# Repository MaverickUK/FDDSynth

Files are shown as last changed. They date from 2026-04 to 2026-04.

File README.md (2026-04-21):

# HDD Synth
<div style="background: white; display: inline-block; padding: 8px;">
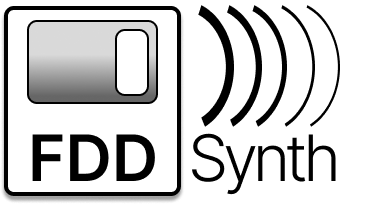
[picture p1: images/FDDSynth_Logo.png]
  
</div>

### Recreates the sound of mechanical spinning FDDs on retro PCs that use a solid state floppy drive.

The first project I created was the [HDD Synth](https://github.com/MaverickUK/HDDSynth) and so bringing the sound back to floppy disk drives felt like the next logical step.

The FDD Synth listens to the signals on the FDD cable that indicate when the motor is spinning and when the head is moving. It essentially recreates those physical actions in software, meaning that when the FDD motor starts spinning the disk it'll play a short spinup sound before a looping spin sound continues. FDD head movement is monitored and replicated with a short click for small movement along with hum of move rapid track changes. 

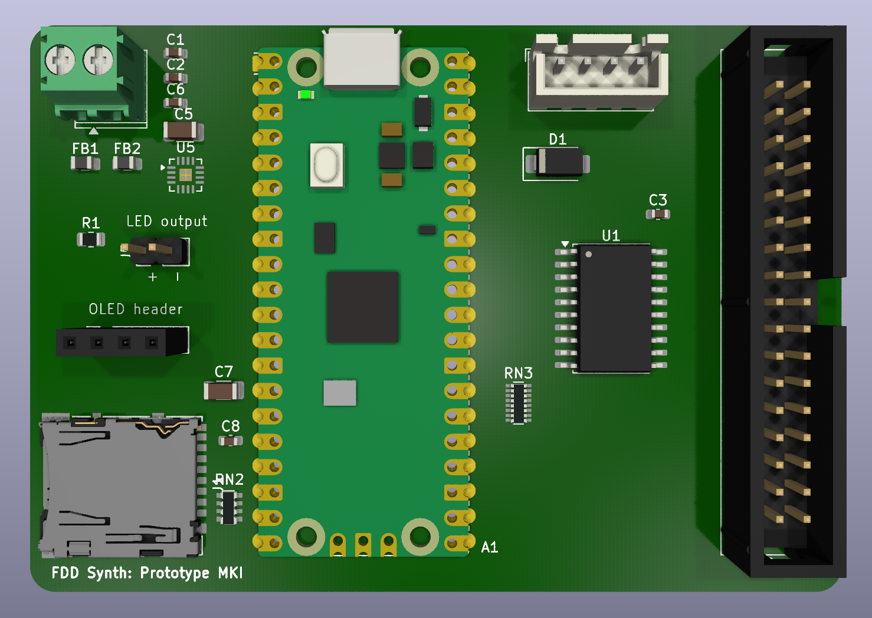
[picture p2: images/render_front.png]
FDD Synth PCB front

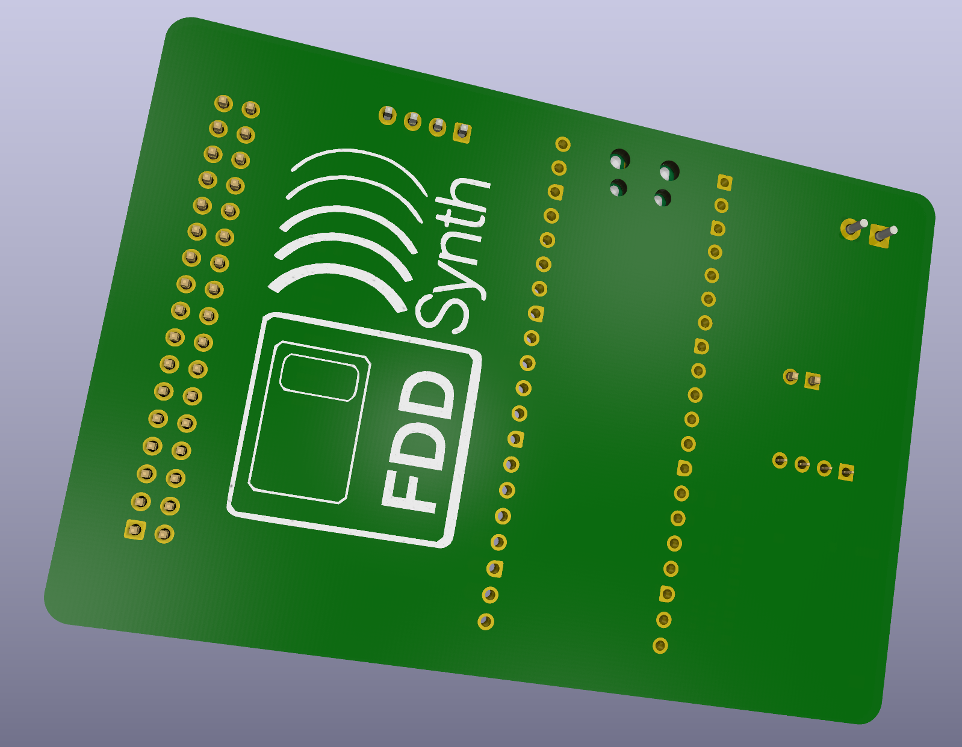
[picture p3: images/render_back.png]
FDD Synth PCB back


## Features

- **Plug and Play**: Uses FDD cable to monitor the exact FDD activity, so all you have to do it plug it in
- **SD Card Storage**: Audio samples stored on removable SD card for easy customization
- **Configurable**: Future software based enhancements planned

## Progress
### 🔄  Phase 1: Breadboard prototype
### 🔄 Phase 2: PCB prototype
### 🌱 Phase 3: PCB final 

<!-- ## Media
[View gallery](media.md) -->

## Contact
Peter Bridger at [maverickuk@gmail.com](maverickuk@gmail.com)

<!--
## Resources

## Acknowledgments
-->

## License
This project is licensed under the GNU General Public License v3.0.

- **Permissions:** Commercial use, modification, and distribution are allowed.
- **Conditions:** You must include a copy of the license and the source code for any derivative works.
- **Prohibitions:** You cannot close the source or use a different license for derivative works.

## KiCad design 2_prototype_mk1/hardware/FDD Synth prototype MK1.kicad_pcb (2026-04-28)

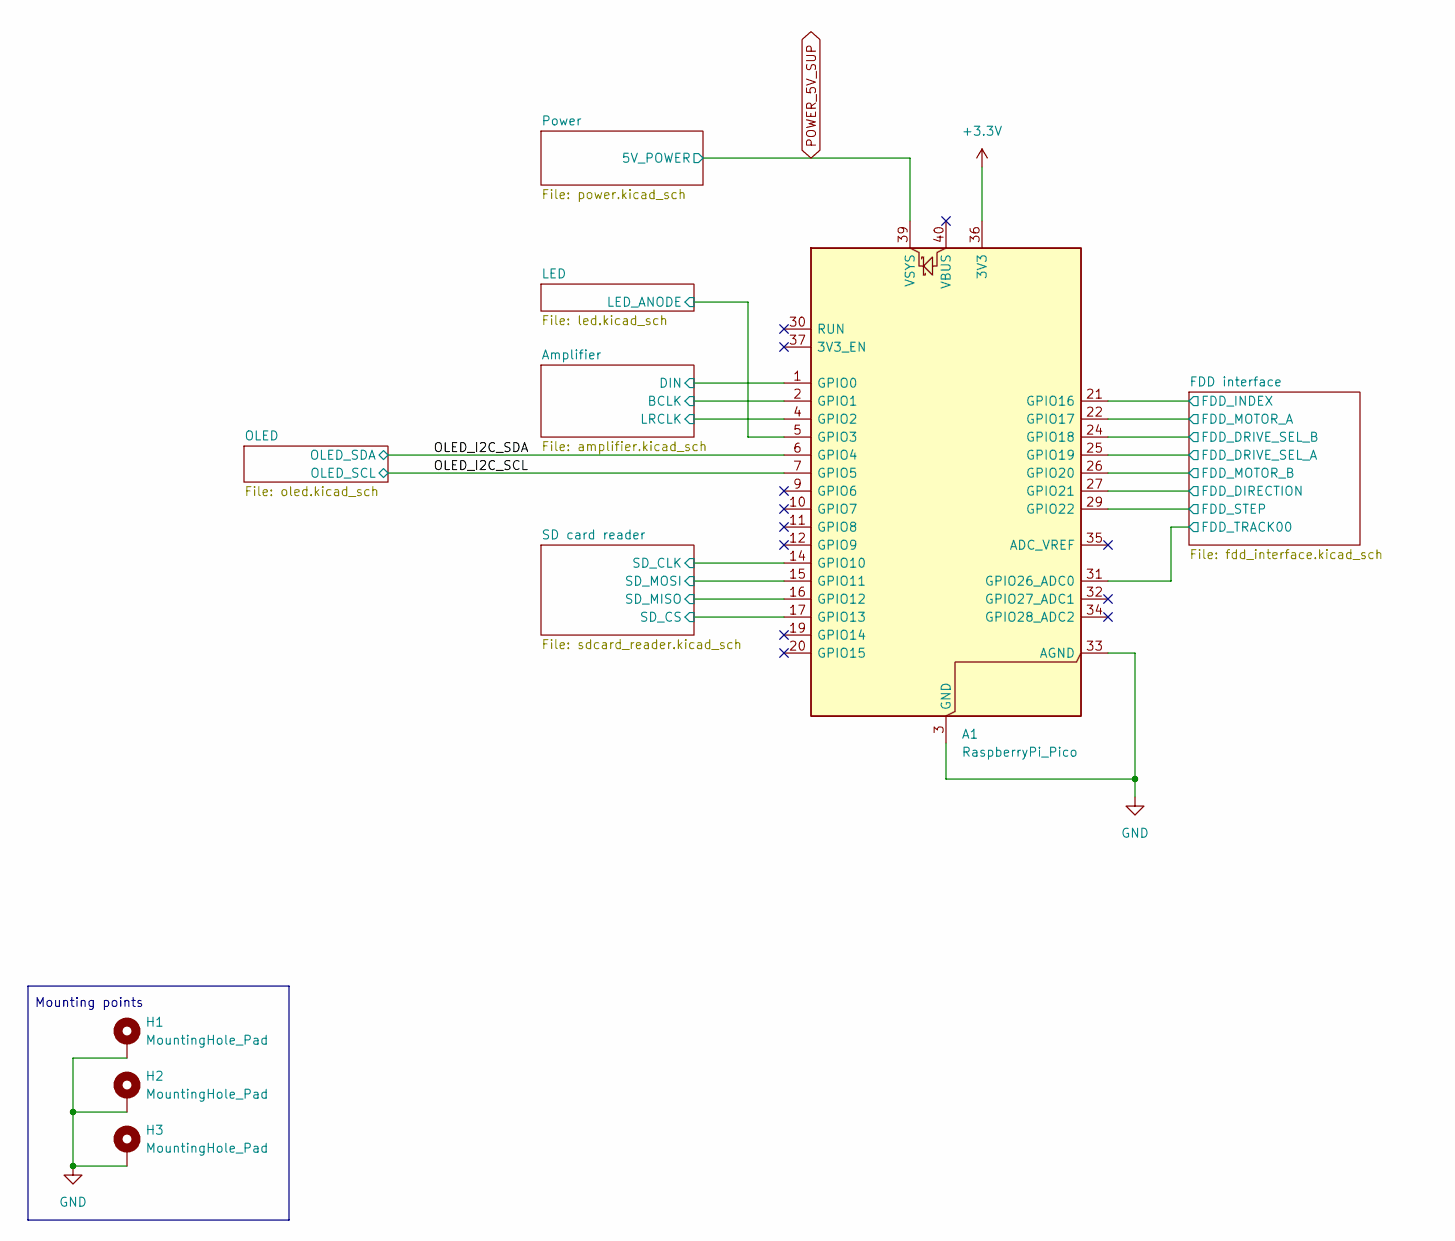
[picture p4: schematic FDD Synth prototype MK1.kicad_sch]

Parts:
A1: RaspberryPi_Pico; RaspberryPi_Pico_Common_Unspecified
H1, H2, H3: MountingHole_Pad; MountingHole_3.2mm_M3_Pad_Via

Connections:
+3.3V: A1.36 (3V3); also elsewhere on the board
/Amplifier/BCLK: A1.2 (GPIO1); also elsewhere on the board
/Amplifier/DIN: A1.1 (GPIO0); also elsewhere on the board
/Amplifier/LRCLK: A1.4 (GPIO2); also elsewhere on the board
/FDD interface/FDD_DIRECTION: A1.27 (GPIO21); also elsewhere on the board
/FDD interface/FDD_DRIVE_SEL_A: A1.25 (GPIO19); also elsewhere on the board
/FDD interface/FDD_DRIVE_SEL_B: A1.24 (GPIO18); also elsewhere on the board
/FDD interface/FDD_INDEX: A1.21 (GPIO16); also elsewhere on the board
/FDD interface/FDD_MOTOR_A: A1.22 (GPIO17); also elsewhere on the board
/FDD interface/FDD_MOTOR_B: A1.26 (GPIO20); also elsewhere on the board
/FDD interface/FDD_STEP: A1.29 (GPIO22); also elsewhere on the board
/FDD interface/FDD_TRACK00: A1.31 (GPIO26_ADC0); also elsewhere on the board
/LED/LED_ANODE: A1.5 (GPIO3); also elsewhere on the board
/OLED_I2C_SCL: A1.7 (GPIO5); also elsewhere on the board
/OLED_I2C_SDA: A1.6 (GPIO4); also elsewhere on the board
/SD card reader/SD_CLK: A1.14 (GPIO10); also elsewhere on the board
/SD card reader/SD_CS: A1.17 (GPIO13); also elsewhere on the board
/SD card reader/SD_MISO: A1.16 (GPIO12); also elsewhere on the board
/SD card reader/SD_MOSI: A1.15 (GPIO11); also elsewhere on the board
GND: A1.3 (GND), A1.8 (GND), A1.13 (GND), A1.18 (GND), A1.23 (GND), A1.28 (GND), A1.33 (AGND), A1.38 (GND), H1.1 (1_1), H2.1 (1_1), H3.1 (1_1); also elsewhere on the board
POWER_5V_SUP: A1.39 (VSYS); also elsewhere on the board

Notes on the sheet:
Mounting points

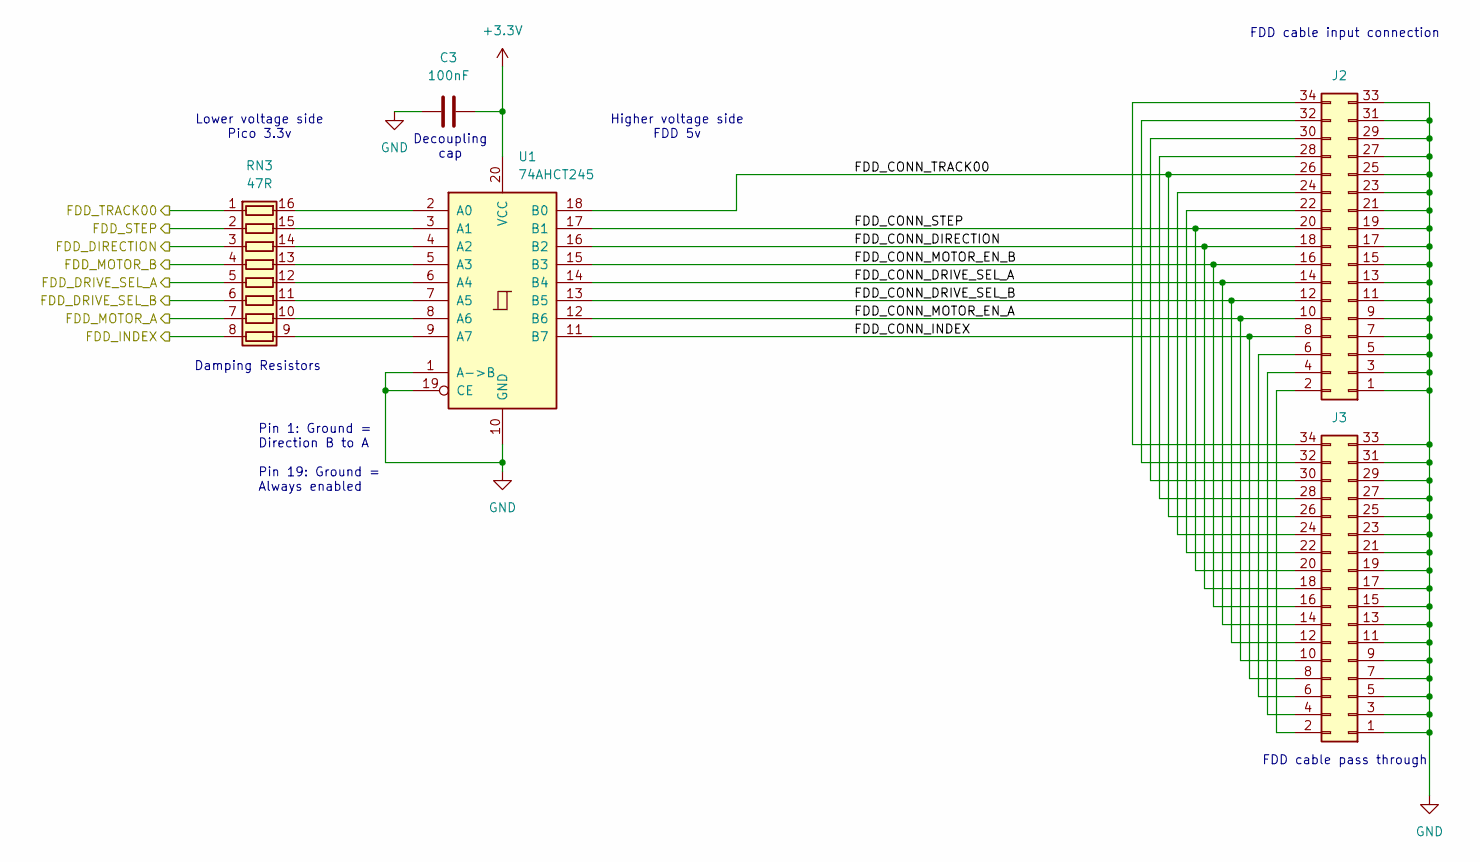
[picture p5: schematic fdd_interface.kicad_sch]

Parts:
C3: 100nF; C_0603_1608Metric
J2, J3: Conn_02x17_Odd_Even; IDC-Header_2x17_P2.54mm_Vertical
RN3: 47R; R_Array_Convex_8x0602
U1: 74AHCT245; SOIC-20W_7.5x12.8mm_P1.27mm

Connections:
+3.3V: C3.2, U1.20 (VCC); also elsewhere on the board
/FDD interface/FDD_CONN_DIRECTION: J2.18, J3.18, U1.16 (B2)
/FDD interface/FDD_CONN_DRIVE_SEL_A: J2.14, J3.14, U1.14 (B4)
/FDD interface/FDD_CONN_DRIVE_SEL_B: J2.12, J3.12, U1.13 (B5)
/FDD interface/FDD_CONN_INDEX: J2.8, J3.8, U1.11 (B7)
/FDD interface/FDD_CONN_MOTOR_EN_A: J2.10, J3.10, U1.12 (B6)
/FDD interface/FDD_CONN_MOTOR_EN_B: J2.16, J3.16, U1.15 (B3)
/FDD interface/FDD_CONN_STEP: J2.20, J3.20, U1.17 (B1)
/FDD interface/FDD_CONN_TRACK00: J2.26, J3.26, U1.18 (B0)
/FDD interface/FDD_DIRECTION: RN3.3 (R3.1); also elsewhere on the board
/FDD interface/FDD_DRIVE_SEL_A: RN3.5 (R5.1); also elsewhere on the board
/FDD interface/FDD_DRIVE_SEL_B: RN3.6 (R6.1); also elsewhere on the board
/FDD interface/FDD_INDEX: RN3.8 (R8.1); also elsewhere on the board
/FDD interface/FDD_MOTOR_A: RN3.7 (R7.1); also elsewhere on the board
/FDD interface/FDD_MOTOR_B: RN3.4 (R4.1); also elsewhere on the board
/FDD interface/FDD_STEP: RN3.2 (R2.1); also elsewhere on the board
/FDD interface/FDD_TRACK00: RN3.1 (R1.1); also elsewhere on the board
GND: C3.1, J2.1, J2.3, J2.5, J2.7, J2.9, J2.11, J2.13, J2.15, J2.17, J2.19, J2.21, J2.23, J2.25, J2.27, J2.29, J2.31, J2.33, J3.1, J3.3, J3.5, J3.7, J3.9, J3.11, J3.13, J3.15, J3.17, J3.19, J3.21, J3.23, J3.25, J3.27, J3.29, J3.31, J3.33, U1.1 (A->B), U1.10 (GND), U1.19 (CE); also elsewhere on the board
unnamed: J2.2, J3.2
unnamed: J2.4, J3.4
unnamed: J2.6, J3.6
unnamed: J2.22, J3.22
unnamed: J2.24, J3.24
unnamed: J2.28, J3.28
unnamed: J2.30, J3.30
unnamed: J2.32, J3.32
unnamed: J2.34, J3.34
unnamed: RN3.16 (R1.2), U1.2 (A0)
unnamed: RN3.15 (R2.2), U1.3 (A1)
unnamed: RN3.14 (R3.2), U1.4 (A2)
unnamed: RN3.13 (R4.2), U1.5 (A3)
unnamed: RN3.12 (R5.2), U1.6 (A4)
unnamed: RN3.11 (R6.2), U1.7 (A5)
unnamed: RN3.10 (R7.2), U1.8 (A6)
unnamed: RN3.9 (R8.2), U1.9 (A7)

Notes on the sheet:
Pin 1: Ground = Direction B to A Pin 19: Ground = Always enabled
Decoupling cap
Damping Resistors
Lower voltage side Pico 3.3v
Higher voltage side FDD 5v
FDD cable input connection
FDD cable pass through

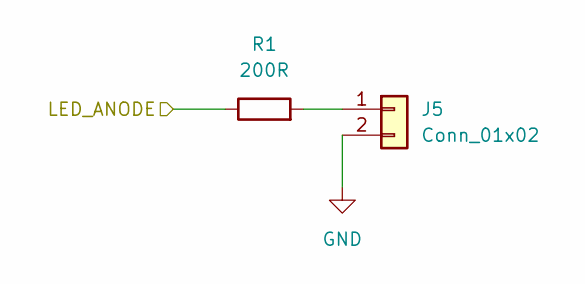
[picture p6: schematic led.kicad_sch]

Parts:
J5: Conn_01x02; PinHeader_1x02_P2.54mm_Vertical
R1: 200R; R_0805_2012Metric

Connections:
/LED/LED_ANODE: R1.1; also elsewhere on the board
GND: J5.2; also elsewhere on the board
unnamed: J5.1, R1.2

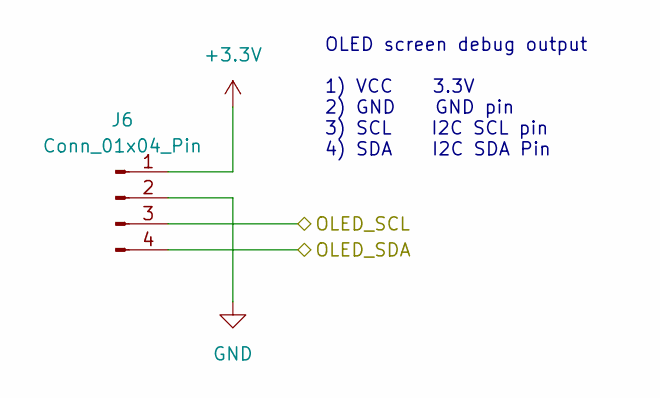
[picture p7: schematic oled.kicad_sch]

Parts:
J6: Conn_01x04_Pin; PinSocket_1x04_P2.54mm_Vertical

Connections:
+3.3V: J6.1; also elsewhere on the board
/OLED_I2C_SCL: J6.3; also elsewhere on the board
/OLED_I2C_SDA: J6.4; also elsewhere on the board
GND: J6.2; also elsewhere on the board

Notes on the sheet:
OLED screen debug output 1) VCC 3.3V 2) GND GND pin 3) SCL I2C SCL pin 4) SDA I2C SDA Pin

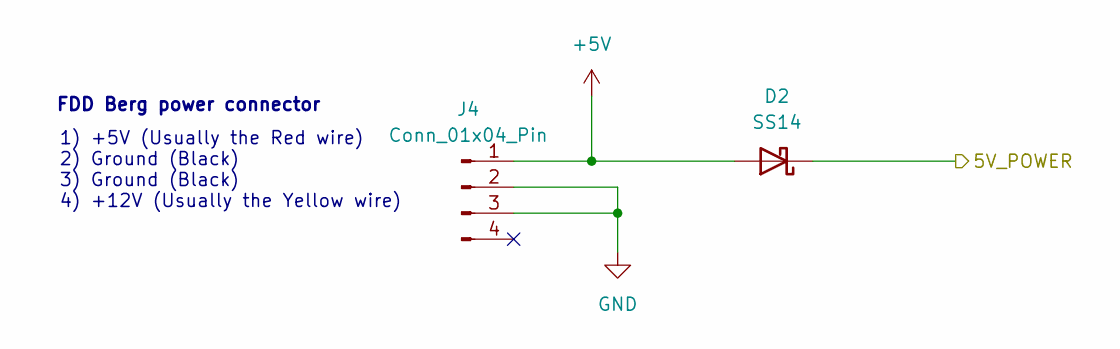
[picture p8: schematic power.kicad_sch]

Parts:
D2: SS14; D_SMA
J4: Conn_01x04_Pin; Molex_KK-254_AE-6410-04A_1x04_P2.54mm_Vertical

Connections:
+5V: D2.2 (A), J4.1
GND: J4.2, J4.3; also elsewhere on the board
POWER_5V_SUP: D2.1 (K); also elsewhere on the board

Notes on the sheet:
FDD Berg power connector
1) +5V (Usually the Red wire) 2) Ground (Black) 3) Ground (Black) 4) +12V (Usually the Yellow wire)

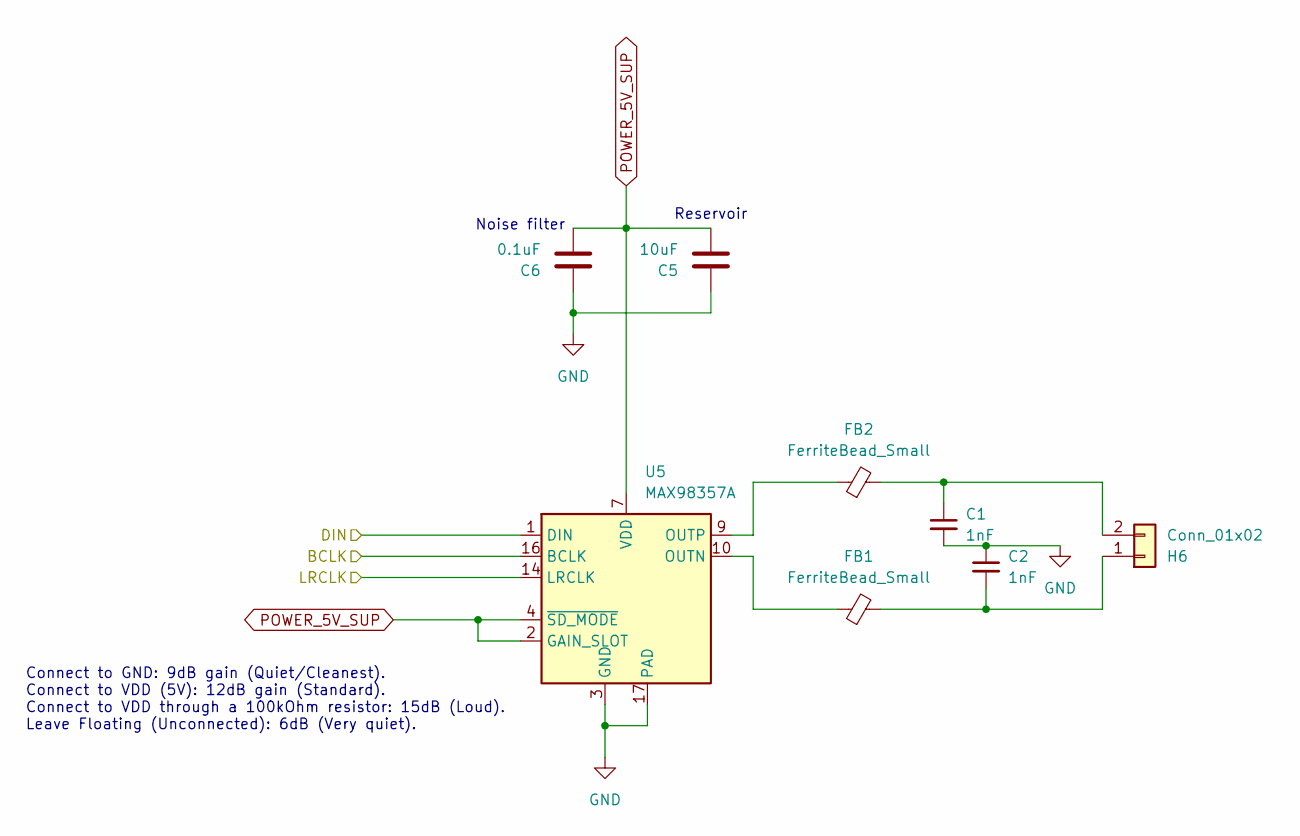
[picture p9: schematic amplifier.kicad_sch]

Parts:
C1, C2: 1nF; C_0603_1608Metric; Manufacturer_Part_Number 0603B102K500NT
C5: 10uF; C_1206_3216Metric; Manufacturer_Part_Number CL31A106KAHNNNE
C6: 0.1uF; C_0603_1608Metric; Manufacturer_Part_Number CL10B104KO8NNNC
FB1, FB2: FerriteBead_Small; L_0805_2012Metric; Manufacturer_Part_Number BLM21PG221SN1D; LCSC_Part_Number C85840
H6: Conn_01x02; TerminalBlock_Phoenix_PT-1,5-2-3.5-H_1x02_P3.50mm_Horizontal; Manufacturer_Part_Number 1984617; LCSC_Part_Number C3819527
U5: MAX98357A; TQFN-16-1EP_3x3mm_P0.5mm_EP1.23x1.23mm; Manufacturer_Part_Number MAX98357AETE+T; LCSC_Part_Number C910544

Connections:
/Amplifier/BCLK: U5.16 (BCLK); also elsewhere on the board
/Amplifier/DIN: U5.1 (DIN); also elsewhere on the board
/Amplifier/LRCLK: U5.14 (LRCLK); also elsewhere on the board
GND: C1.2, C2.1, C5.1, C6.1, U5.3 (GND), U5.11 (GND), U5.15 (GND), U5.17 (PAD); also elsewhere on the board
unnamed: C2.2, FB1.2, H6.1
unnamed: C1.1, FB2.2, H6.2
unnamed: FB1.1, U5.10 (OUTN)
unnamed: FB2.1, U5.9 (OUTP)
POWER_5V_SUP: C5.2, C6.2, U5.2 (GAIN_SLOT), U5.4 (~SD_MODE), U5.7 (VDD), U5.8 (VDD); also elsewhere on the board

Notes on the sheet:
Connect to GND: 9dB gain (Quiet/Cleanest). Connect to VDD (5V): 12dB gain (Standard). Connect to VDD through a 100kOhm resistor: 15dB (Loud). Leave Floating (Unconnected): 6dB (Very quiet).
Reservoir
Noise filter

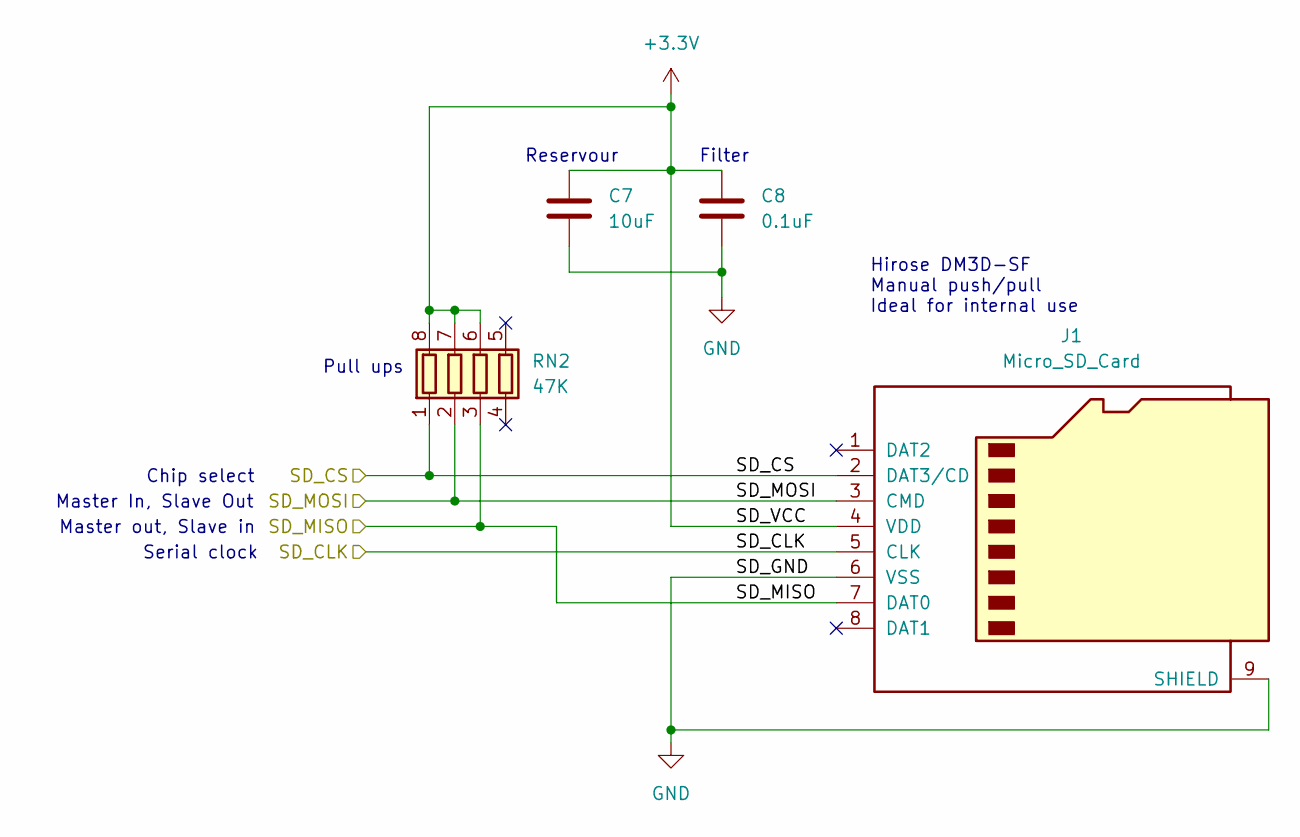
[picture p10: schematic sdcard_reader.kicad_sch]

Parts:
C7: 10uF; C_1206_3216Metric; Manufacturer_Part_Number CL31A106KAHNNNE
C8: 0.1uF; C_0603_1608Metric; Manufacturer_Part_Number CL10B104KO8NNNC
J1: Micro_SD_Card; microSD_HC_Hirose_DM3D-SF; Manufacturer_Part_Number DM3D-SF; LCSC_Part_Number C719027
RN2: 47K; R_Array_Convex_4x0603; Manufacturer_Part_Number YC164-JR-0747KL; LCSC_Part_Number C779384

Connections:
+3.3V: C7.1, C8.1, J1.4 (VDD), RN2.6 (R3.2), RN2.7 (R2.2), RN2.8 (R1.2); also elsewhere on the board
/SD card reader/SD_CLK: J1.5 (CLK); also elsewhere on the board
/SD card reader/SD_CS: J1.2 (DAT3/CD), RN2.1 (R1.1); also elsewhere on the board
/SD card reader/SD_MISO: J1.7 (DAT0), RN2.3 (R3.1); also elsewhere on the board
/SD card reader/SD_MOSI: J1.3 (CMD), RN2.2 (R2.1); also elsewhere on the board
GND: C7.2, C8.2, J1.6 (VSS), J1.9 (SHIELD); also elsewhere on the board

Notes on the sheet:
Master In, Slave Out
Pull ups
Filter
Chip select
Master out, Slave in
Reservour
Serial clock
Hirose DM3D-SF Manual push/pull Ideal for internal use

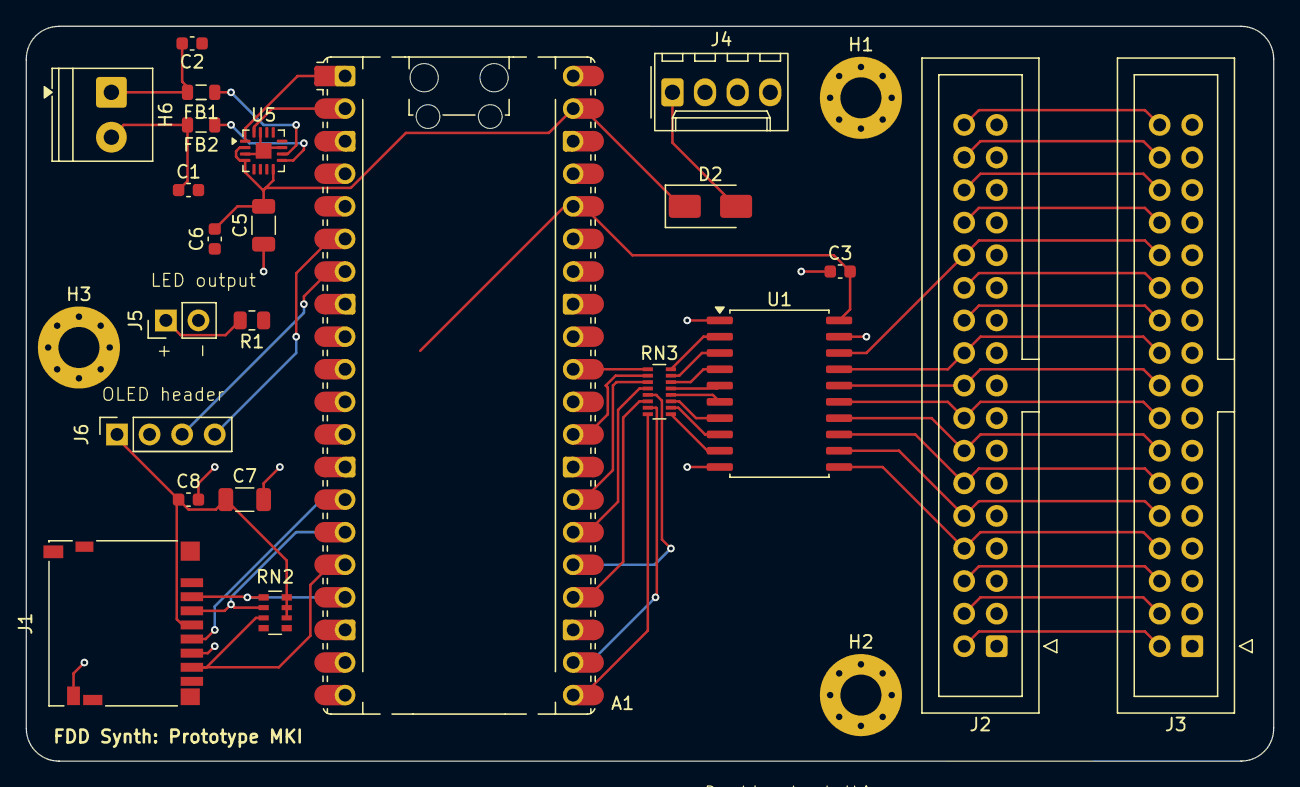
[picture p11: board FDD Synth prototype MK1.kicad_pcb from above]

Board: 2 copper layers, 97.2 x 57.3 mm, 26 parts (0 on the bottom side), 52 nets.

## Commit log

2026-04-20 Create basic starting point of design
    [FDD Synth prototype MK1.kicad_pcb, FDD Synth prototype MK1.kicad_sch, amplifier.kicad_sch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]
2026-04-21 Created basic PCB
    [FDD Synth prototype MK1.kicad_pcb, FDD Synth prototype MK1.kicad_sch, amplifier.kicad_sch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]
2026-04-21 Add OLED screen header
    [FDD Synth prototype MK1.kicad_pcb, FDD Synth prototype MK1.kicad_sch]
2026-04-21 Create LED and OLED connections
    [FDD Synth prototype MK1.kicad_pcb, FDD Synth prototype MK1.kicad_sch, led.kicad_sch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]
2026-04-21 Add PCB renders to README
2026-04-23 Quick and dirty layout of traces - not final
    [FDD Synth prototype MK1.kicad_pcb, FDD Synth prototype MK1.kicad_sch]
2026-04-24 Switch out SD card reader for correct footprint
    [FDD Synth prototype MK1.kicad_pcb, sdcard_reader.kicad_sch]
2026-04-28 Split power into own schematic
    [FDD Synth prototype MK1.kicad_pcb, FDD Synth prototype MK1.kicad_sch, fdd_interface.kicad_sch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]
2026-04-28 Change power connector and reroute amp
    [FDD Synth prototype MK1.kicad_pcb, FDD Synth prototype MK1.kicad_sch, fdd_interface.kicad_sch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]
